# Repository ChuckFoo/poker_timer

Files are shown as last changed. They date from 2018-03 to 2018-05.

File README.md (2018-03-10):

A little standalone poker blind timer project.

The basic idea is based on an Arduino mini/pro micro/nano (or perhaps a Teensy, or a Maple
Mini), battery powered (4x AA or AAA), includes an [SD
card](https://www.amazon.com/gp/product/B06XRD9LH5/) based configuration, an
[OLED](https://www.amazon.com/gp/product/B01HHPOD44/) screen to show the time
left in the round and the blind values, a [piezo
buzzer](https://www.amazon.com/gp/product/B0727VHH67/) to signal the round
changes, some buttons to control it (start/pause, prev round, next round), and
a 3D printed custom case designed using
[OpenSCAD](https://github.com/openscad/openscad/) and
[text_on_OpenSCAD](https://github.com/brodykenrick/text_on_OpenSCAD).

Status as of 20180309

Here's about what the OpenSCAD design looks like (using "show off" setting in the script):

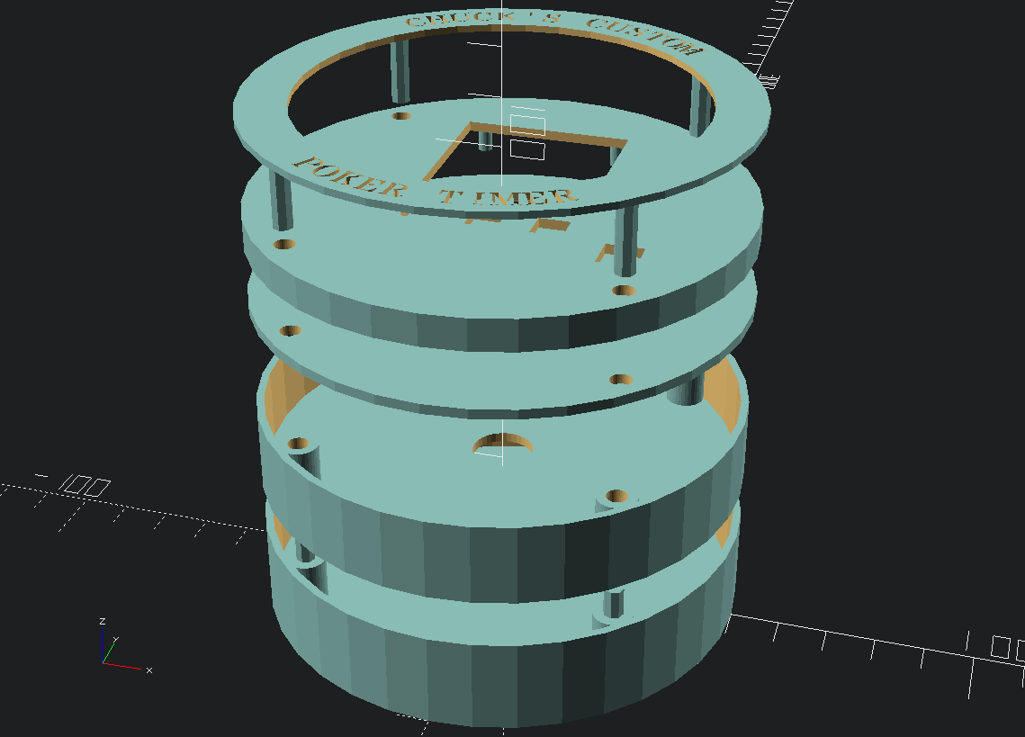
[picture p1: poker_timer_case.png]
OpenSCAD preview of all the case components


and I've gone through a few changes along the way...the initial version of the top parts looked like this:

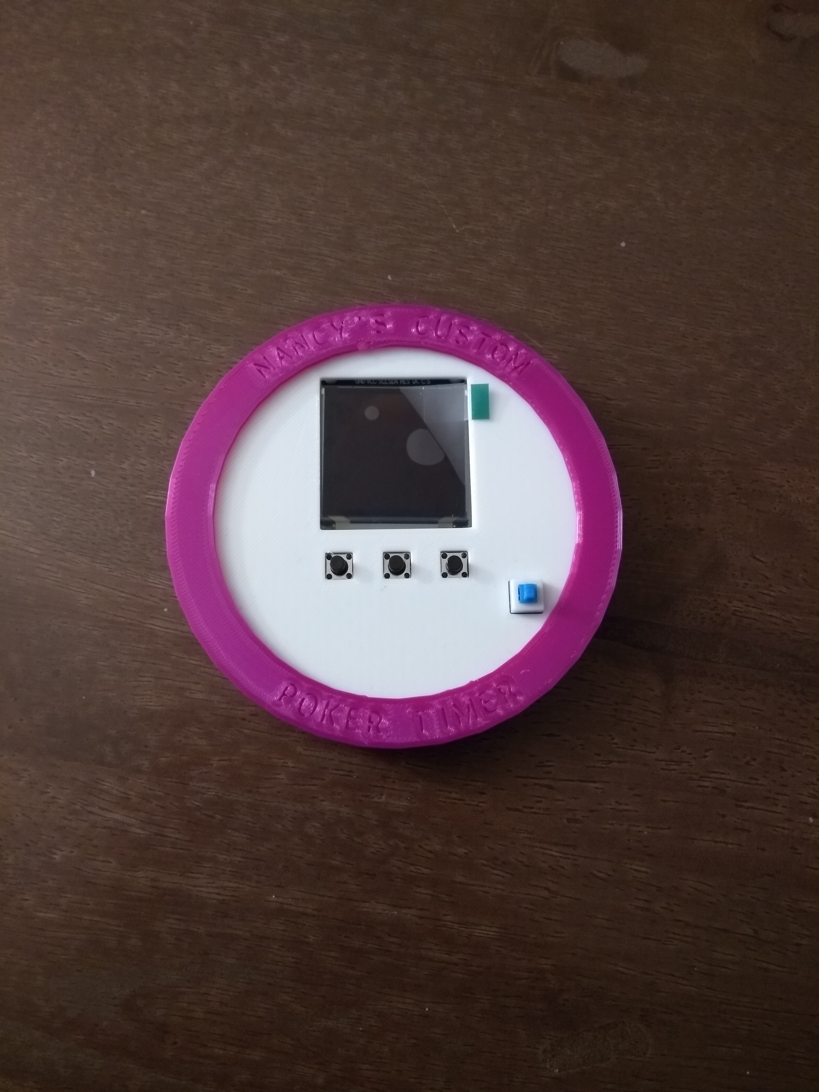
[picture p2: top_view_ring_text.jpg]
Top ring w/ text test

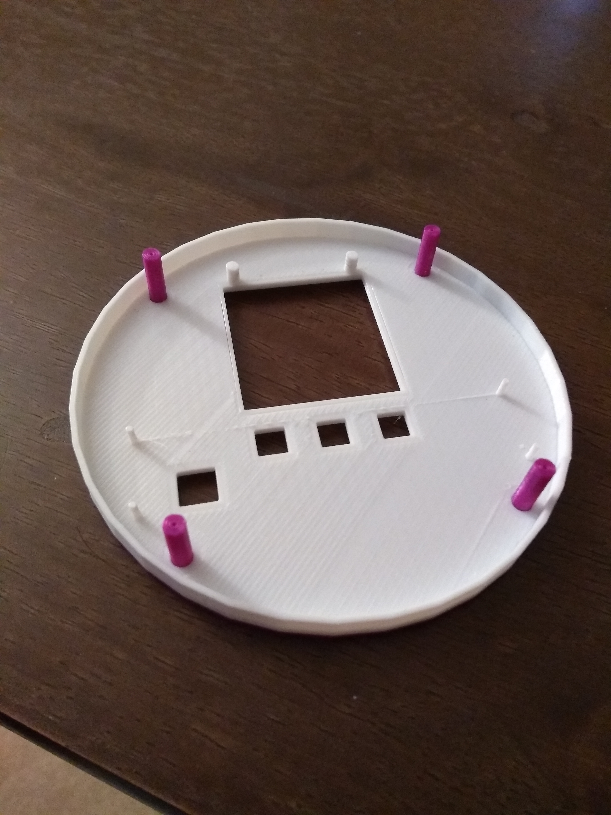
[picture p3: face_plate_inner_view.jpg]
face plate inner view

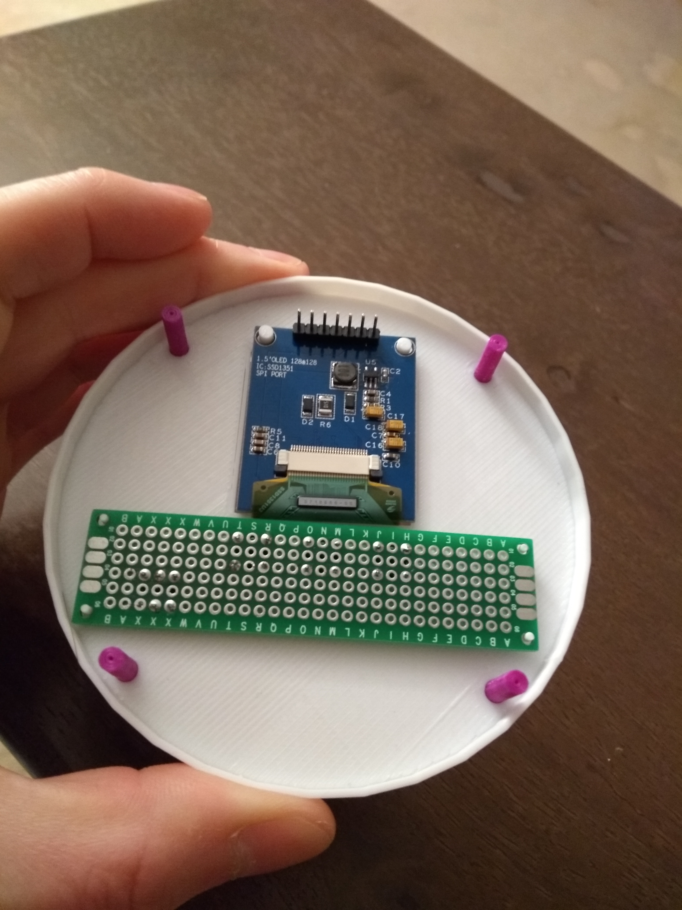
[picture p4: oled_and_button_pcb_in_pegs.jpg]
OLED and button pcb on pegs in face plate

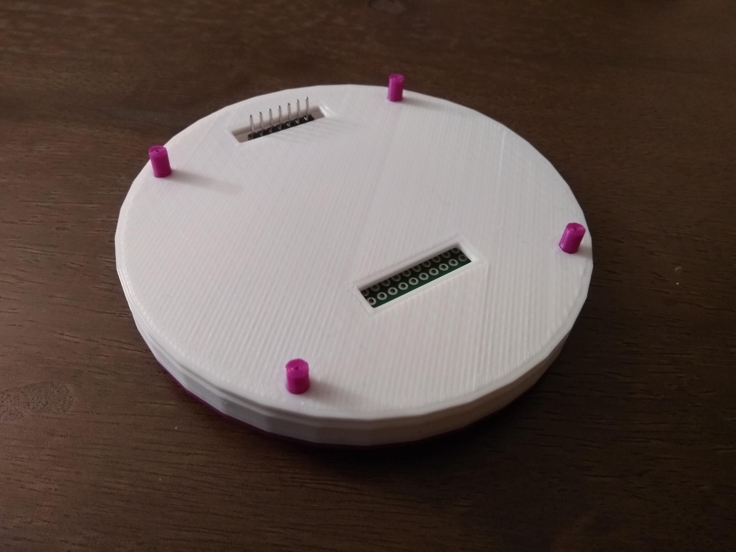
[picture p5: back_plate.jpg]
Back plate


Which wasn't bad, but the text was difficult to get to look right, so I went
with suits instead (which still have their issues but overall look better I
think).  Here's what it, and the 2 remaining pieces ended up as (currently):

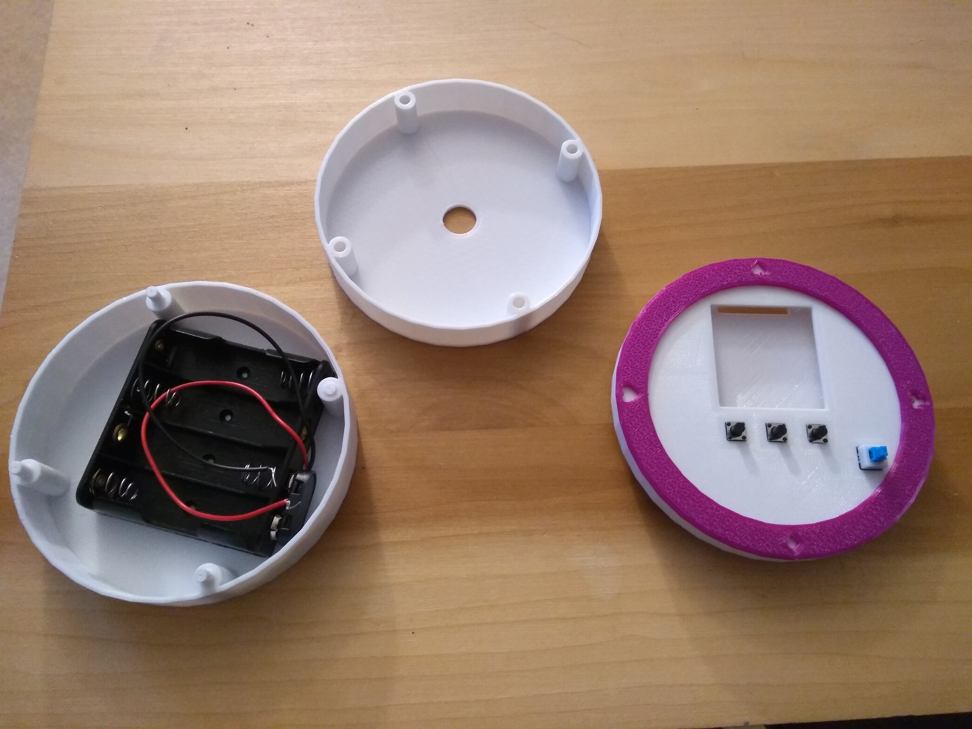
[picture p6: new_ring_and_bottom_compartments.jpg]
New ring & bottom compartments


And all put together it looks like:

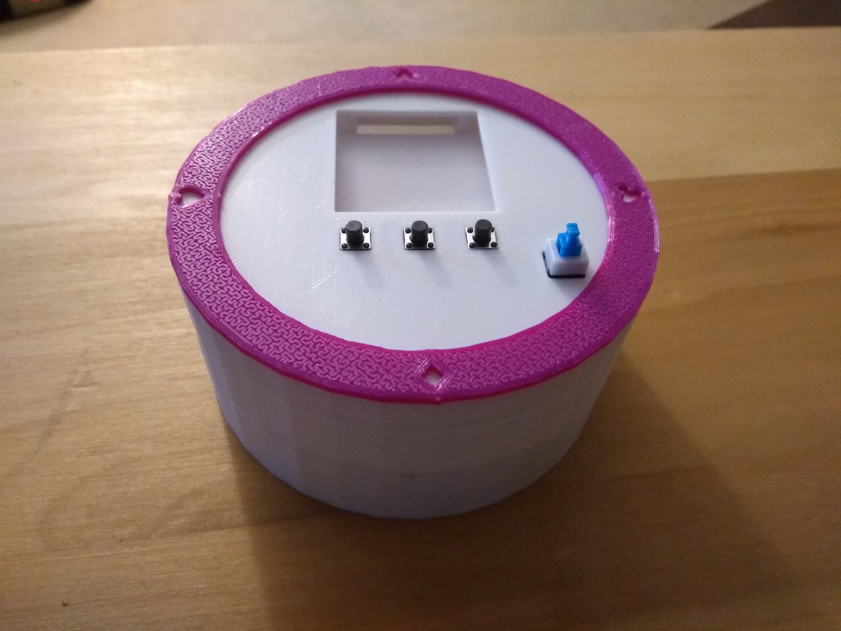
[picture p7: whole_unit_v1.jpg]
whole unit, initial version


But it's looking a little...thick.  So I might just go without the battery
compartment, and switch to AAA batteries which should fit in the electronics
compartment w/ the electronics:

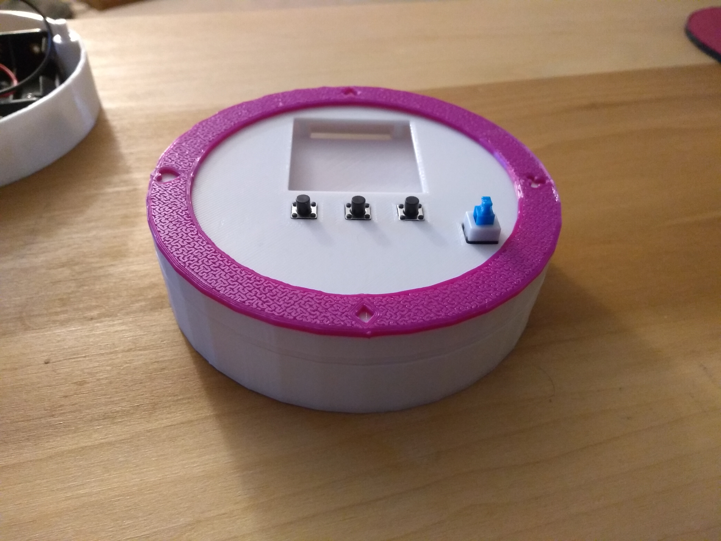
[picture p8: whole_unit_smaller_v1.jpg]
whole unit, smaller variant


And speaking of the electronics, here's what the prototype version is looking like:

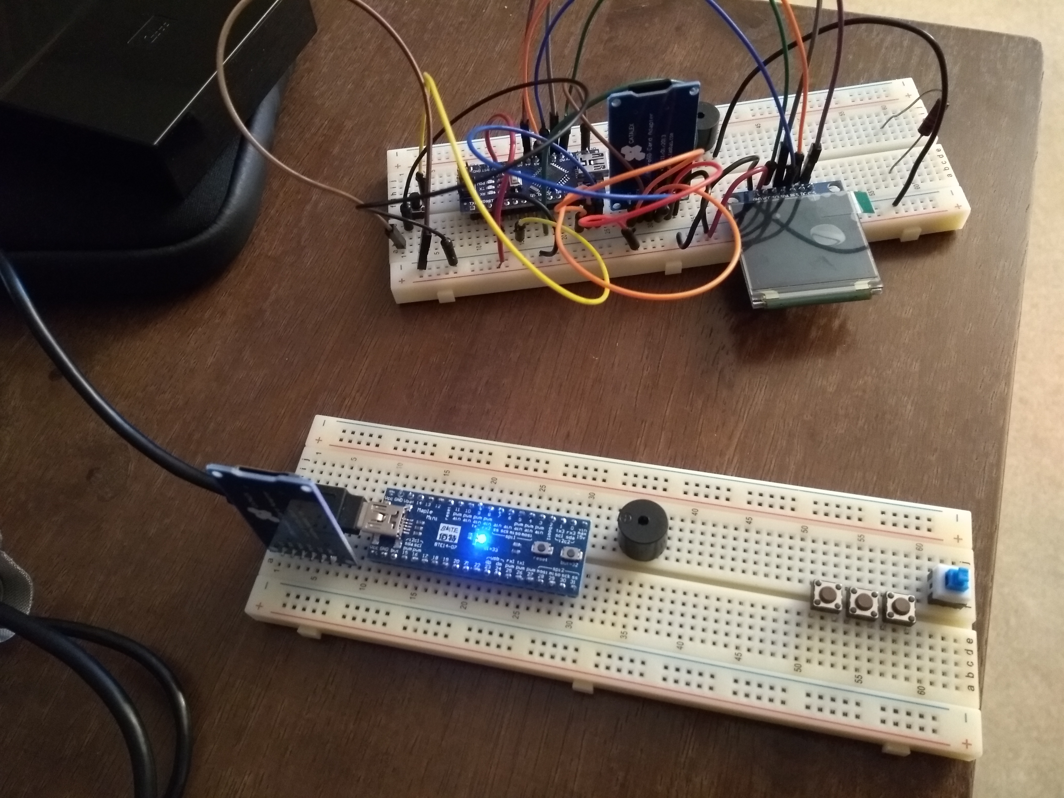
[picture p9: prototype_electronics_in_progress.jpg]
A work in progress...


The top one that is wired up is based on an Arduino Nano clone, and I think
I'm hitting some issues that may be related to eating up nearly all of RAM
(uploading the sketch in progress complains that it is ~80% full due to
globals leaving only a little for runtime) while running, so I've decided to
switch to a Maple Mini clone (lower breadboard not wired up yet), giving me a
lot more RAM and Flash to work with, as well as a faster processor and a 2nd
HW I2C peripheral (which I hope will help with the I2C graphics updates).

I'll upload the sketch as I make more progress on it...

And after that's ready, I may revisit the design of the base.  The peg & hole
method is okay, but has issues (and I busted off one pin because of them
accidentally) so I'm thinking of trying an alternate connection approach (like
screw threads or a bayonet type connector).

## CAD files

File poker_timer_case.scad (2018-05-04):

// case for my custom poker timer (uncomment individual parts & Render to generate STL)

// note: 0.1 inch is 2.54mm, my protoboards (buttons are on) have 0.1"
// spacing, so handy to use that conversion to help calculate offsets
// (combined w/ lots of measuring).

use <text_on/text_on.scad>

RESOLUTION = 36; // how nice to draw the circles
$fn = RESOLUTION;

MAIN_RADIUS = 50; // radius of case

RING_RADIUS = 50; // radius of the ring
RING_WIDTH = 10; // width of the ring
RING_HEIGHT = 1.4; // height of the ring
RING_PEG_HEIGHT = 15+RING_HEIGHT;

PEG_RADIUS = 2;
PEG_HOLE_RADIUS = PEG_RADIUS+0.1; // need a little extra for the holes to get the pegs to fit
PEG_RES = 8; // octagon pegs + the 0.1mm extra radius in the holes seem to work good w/ my tests
PEG_HOLE_RES = 36;

// I'd like to put some Unicode playing card characters around the ring, but
// can't because because of the border, that'll make the centers completely
// fall out...so just the suits will work I guess.  Or some text (with a
// stencil font, to keep the centers from falling out).
ACES = "🂡🂱🃁🃑"; // why do these look different here in emacs than in the
                // openscad editor when I'm using the same font in both?
SUITS = "♠♥♦♣";
SUIT_SIZE = 7;
SUIT_FONT = "DejaVuSansMono";

// set this to draw the suit glyphs, otherwise text
DO_SUITS = 1;

TEXT_TOP = "CHUCK'S CUSTOM";
TEXT_BOTTOM = "POKER TIMER";
TEXT_SIZE = 5;
TEXT_SPACING = 1.2;

FONT = "StardosStencil-Bold";
//FONT = "SirinStencil-Regular"; // I like this font, but it's too thin to work effectively unfortunately...

module top_ring() {
  // drawing the ring using cylinder:
  difference() {
    cylinder(r = RING_RADIUS, h = RING_HEIGHT);

    // now the cutouts: added a little to the height for the difference
    // cylinder & suits to make odd display issues w/ preview go away.  BTW,
    // for some reason the center=false isn't really working on the
    // text_on_circle, so the extrusion is always centered on Z=0?

    if (DO_SUITS) {
      for (i = [0,1,2,3]) {
        text_on_circle(t=SUITS[i],r=RING_RADIUS-RING_WIDTH/2,font=SUIT_FONT,size=SUIT_SIZE,rotate=i*90,halign="center",valign="center",extrusion_height=RING_HEIGHT*4);
      }
    } else {
      // text, backwards so it looks right when printed & used:
      rotate([0,180,0]){
        text_on_circle(t=TEXT_TOP,r=RING_RADIUS-RING_WIDTH/2,font=FONT,size=TEXT_SIZE,spacing=TEXT_SPACING,valign="baseline",extrusion_height=RING_HEIGHT*4);
        text_on_circle(t=TEXT_BOTTOM,r=RING_RADIUS-RING_WIDTH/2,font=FONT,size=TEXT_SIZE,spacing=TEXT_SPACING,valign="baseline",extrusion_height=RING_HEIGHT*4,ccw=true);
      }
    }

    // cut out the middle
    cylinder(r = RING_RADIUS - RING_WIDTH, h = RING_HEIGHT*4,center=true); 
  }
  draw_pegs(RING_PEG_HEIGHT,PEG_RADIUS,0,PEG_RES);
}

module draw_pegs(h,r,zoff,fn) {
  $fn = fn;
  // now the pegs, first need to locate where to put them (45 degrees off the
  // cardinals) by using a little math...
  peg_offset = sin(45) * (RING_RADIUS - (RING_WIDTH/2));
  for (x = [-peg_offset,peg_offset]) {
    for (y = [-peg_offset,peg_offset]) {
      translate([x,y,zoff]) {
        cylinder(r=r,h=h);
      }
    }
  }
}

OLED_W = 34;
OLED_H = 36;
OLED_X = 0;
OLED_Y = 15;
OLED_PEG_R = 1.4; // pegs are approx r=1.5, 28.5mm apart, centered 1.8mm above top of OLED
OLED_PEG_Y = OLED_Y + OLED_H/2 + 1.8;
OLED_PEGS = [[-14.25,OLED_PEG_Y],[14.25,OLED_PEG_Y]];

BUTTON_SIDE = 6.3; // 6 w/ a little more room to fit through
BUTTON_Xs = [-12.7,0,12.7]; // button centers .5" or 12.7mm apart
BUTTON_Y = -11;
// the pegs need to be approx 76mm apart in the x, 16mm apart in the y ;
// leftmost x is 11.5mm off the middle of power switch ; bottom y is 4.2mm
// lower than power switch middle, top y is 4.2mm higher than button middle.
BUTTON_PEGS = [[-39,BUTTON_Y+4.2],[37,BUTTON_Y+4.2],[-39,BUTTON_Y-11.8],[37,BUTTON_Y-11.8]];
BUTTON_PEG_R = 0.6;

// power swtich center is -15.24 from leftmost button
POWER_W = 7.5;
POWER_H = 7.5;
POWER_X = BUTTON_Xs[0]-15.24;
POWER_Y = BUTTON_Y-7.62;
FACE_THICK = 2;
FACE_RIM = 1.2;
FACE_RIM_THICK = FACE_THICK+4.5;

module face_plate() {
  difference() {
    cylinder(r = RING_RADIUS, h = FACE_THICK);
    // square hole for OLED:
    translate([OLED_X,OLED_Y,0]) {
      cube([OLED_W,OLED_H,FACE_THICK*4], center=true);
    }
    // and some buttons (with square bases):
    for (x=BUTTON_Xs) {
      translate([x,BUTTON_Y,0]) {
        cube([BUTTON_SIDE,BUTTON_SIDE,FACE_THICK*4],center=true);
      }
    }
    // and the power switch (actually, a toggle button now):
    translate([POWER_X,POWER_Y]) {
      cube([POWER_W,POWER_H,FACE_THICK*4],center=true);
    }
    // now the peg holes:
    draw_pegs(FACE_THICK+1,PEG_HOLE_RADIUS,-1,PEG_HOLE_RES);
  }
  // add pegs to secure OLED and buttons (vector of x/y pairs):
  // (note not real values yet)
  for (peg = OLED_PEGS) {
    translate([peg[0],peg[1]]) {
      cylinder(r=OLED_PEG_R,h=FACE_RIM_THICK);
    }
  }
  for (peg = BUTTON_PEGS) {
    translate([peg[0],peg[1]]) {
      cylinder(r=BUTTON_PEG_R,h=FACE_RIM_THICK);
    }
  }
  // how about a ring around the edge to hide the gap?
  difference() {
    cylinder(r=RING_RADIUS,h=FACE_RIM_THICK);
    cylinder(r=RING_RADIUS-FACE_RIM,h=FACE_THICK*4);
  }
}

BACK_PLATE_THICK = 2;
// OLED pins are centered X 16mm wide, Y at top of oled support pegs (about 1mm)
OLED_PINS_W = 25;
OLED_PINS_H = 6;

module back_plate() {
  difference() {
    cylinder(r = RING_RADIUS, h = BACK_PLATE_THICK);
    // need some holes for OLED pins, maybe just a rectangle, and make it a
    // little bigger than just the pins, to run button/switch wires through
    // too:
    translate([OLED_X,OLED_PEG_Y+OLED_PEG_R]) {
      cube([OLED_PINS_W,OLED_PINS_H,BACK_PLATE_THICK*4],center=true);
    }
    // might want a second one for the button wires actually:
    translate([0,BUTTON_Y-BUTTON_SIDE-5]) {
      cube([OLED_PINS_W,OLED_PINS_H,BACK_PLATE_THICK*4],center=true);
    }
    // now the peg holes:
    draw_pegs(BACK_PLATE_THICK*2,PEG_HOLE_RADIUS,-1,PEG_HOLE_RES);
  }
}

ELECTRONICS_HEIGHT = 17;
ELECTRONICS_RING_WIDTH = 1.6;

module electronics_compartment() {
  difference() {
    cylinder(r = RING_RADIUS, h = ELECTRONICS_HEIGHT);
    // cut out the middle, but leave some room
    cylinder(r = RING_RADIUS - ELECTRONICS_RING_WIDTH, h = ELECTRONICS_HEIGHT*4,center=true); 
  }
  // put in posts w/ holes for pegs:
  difference() {
    draw_pegs(ELECTRONICS_HEIGHT,PEG_RADIUS*2,0,PEG_HOLE_RES);
    // holes
    draw_pegs(ELECTRONICS_HEIGHT,PEG_HOLE_RADIUS,0,PEG_HOLE_RES);
  }
  // now the bottom plate:
  difference() {
    cylinder(r = RING_RADIUS, h = 2);
    // need the peg holes too:
    draw_pegs(ELECTRONICS_HEIGHT+1,PEG_HOLE_RADIUS,0,PEG_HOLE_RES);
    // and a hole for wires to the battery & sd card
    cylinder(r = PEG_HOLE_RADIUS*3,h = 4);
  }
}

BATTERY_RING_WIDTH = 1.6;
BATTERY_HEIGHT = 20;
BATTERY_PEG_HEIGHT = 7;

module battery_compartment() {
  difference() {
    cylinder(r = RING_RADIUS, h = BATTERY_HEIGHT);
    // cut out the middle
    cylinder(r = RING_RADIUS - BATTERY_RING_WIDTH, h = BATTERY_HEIGHT*4,center=true); 
  }
  // now the bottom plate:
  cylinder(r = RING_RADIUS, h = 2);
  // and peg supports + pegs:
  draw_pegs(BATTERY_HEIGHT,PEG_RADIUS*2,0,PEG_HOLE_RES);
  draw_pegs(BATTERY_PEG_HEIGHT,PEG_RADIUS,BATTERY_HEIGHT-1,PEG_RES);
}

// 3x button covers...10mm diameter, 3.4mm diameter hole?

// for a "big display" (to create an overview image, for example), set
// SHOW_OFF to 1, otherwise uncomment a part at a time in the next section,
// render, and generate STL files for each part...
SHOW_OFF = 1;

if (SHOW_OFF) {
  translate([0,0,110]) {
    rotate([0,180,0]) {
      color("MediumPurple") top_ring();
    }
  }
  translate([0,0,90]) {
    rotate([0,180,0]) {
      color("White") face_plate();
    }
  }
  translate([0,0,70]) {
    color("White") back_plate();
  }
  translate([0,0,30]) {
    color("White") electronics_compartment();
  }
  translate([0,0,0]) {
    color("White") battery_compartment();
  }
  // add button covers positioned over the 3 square button holes in the face
  // plate...  start/pause red?  Or all white?
} else {
  // uncomment part to create:

  top_ring();
  //face_plate();
  //back_plate();
  //electronics_compartment();
  //battery_compartment();
  //button_covers();

}

              

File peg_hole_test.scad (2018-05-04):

// make a couple of r=2mm pegs to try w/ varying numbers of sides

module make_peg(r,fn) {
  h=10;
  cylinder(r=r, h=h, $fn=fn);
}

module make_pegs(r) {
  translate([-15,0,0]) make_peg(r,6);
  translate([0,0,0]) make_peg(r,8);
  translate([15,0,0]) make_peg(r,100); // effectively round
  cube([45,10,2],center=true);
}

module make_hole(r,fn) {
  cylinder(r=r,h=5,center=true,$fn=fn);
}


module make_holes(r,fn) {
  difference() {
    cube([45,10,2],center=true);
    for (i=[0,1,2,3,4,5]) {
      translate([-18+i*7,0,0]) {
        make_hole(r+(i/20),fn);
      }
    }
  }
}

// make some pegs, r=2mm, with a couple of different number of sides
//make_pegs(2);

// now make some holes (round) starting at r=2mm and increasing by .05mm
//translate([0,-15,0]) {
//  make_holes(2,100);
//}

// for some button covers the button post is round and about 3.34mm diameter,
// so need to test some not round holes starting at half that radius...
//translate([0,-30,0]) {
  bcr = 1.8; // 3.4mm diameter -> 1.7mm radius, pad it slightly to 1.8mm?
  make_holes(bcr,12);
//}

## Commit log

2018-03-03 Initial version of OpenSCAD code
    [poker_timer_case.scad]
2018-03-03 adding peg test OpenSCAD code
    [peg_hole_test.scad]
2018-03-10 added status pics and minor updates to the scad script
    [poker_timer_case.scad]
2018-05-04 started to do button covers but realized the case needs some structural redesign first, so committing before doing that
    [peg_hole_test.scad, poker_timer_case.scad]
